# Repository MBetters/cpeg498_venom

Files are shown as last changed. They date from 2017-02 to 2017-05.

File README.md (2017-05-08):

# What Is This?
Hola. This is a UD capstone design repo for a robot spider. AKA Project Venom.

# Directories
- `spider_server`: this is a python web server that acts as the user's controller. It is hosted on c9.io.
- `spider_raspberry_pi`: this is the python code for a WiFi-connected Raspberry Pi that continuously polls `spider_server` for the latest user commands while simultaneously transmitting these commands over a serial line to the Arduino.
- `spider_arduino`: this is the Arduino code that continually listens for new commands from the serial input line from the Raspberry Pi and then translates those commands into servo signals that move the robot spider's legs.
- `spider_body`: this is STL files for 3D-printing the spider

# Summary
`spider_server` <--(WiFi)--> `spider_raspberry_pi` <--(USB)--> `spider_arduino` <--(PWM)--> servos

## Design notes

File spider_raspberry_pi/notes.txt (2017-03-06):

Installation Instructions:
pip install pyserial

Links:
http://www.ics.com/blog/raspberry-pi-camera-module#.VJFhbyvF-b8

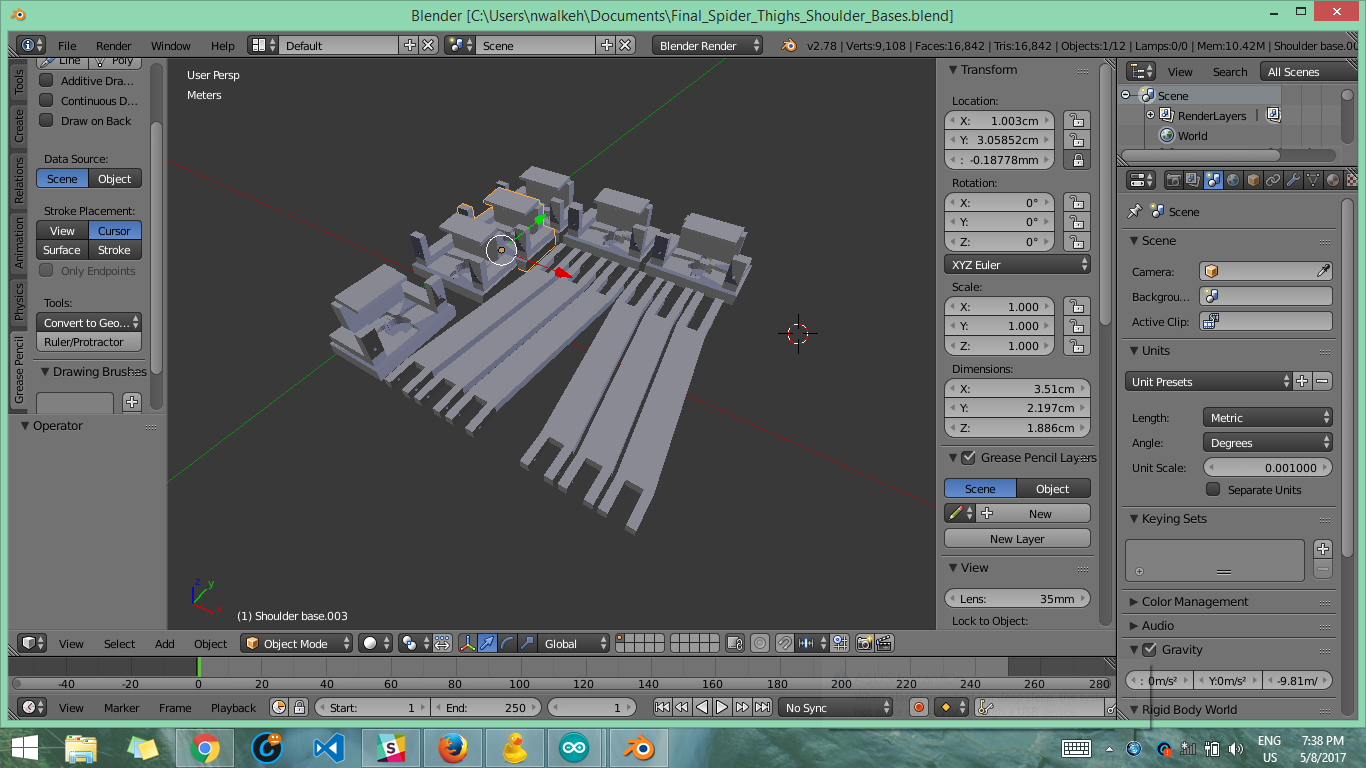
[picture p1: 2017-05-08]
spider_body/Screenshot (262).png

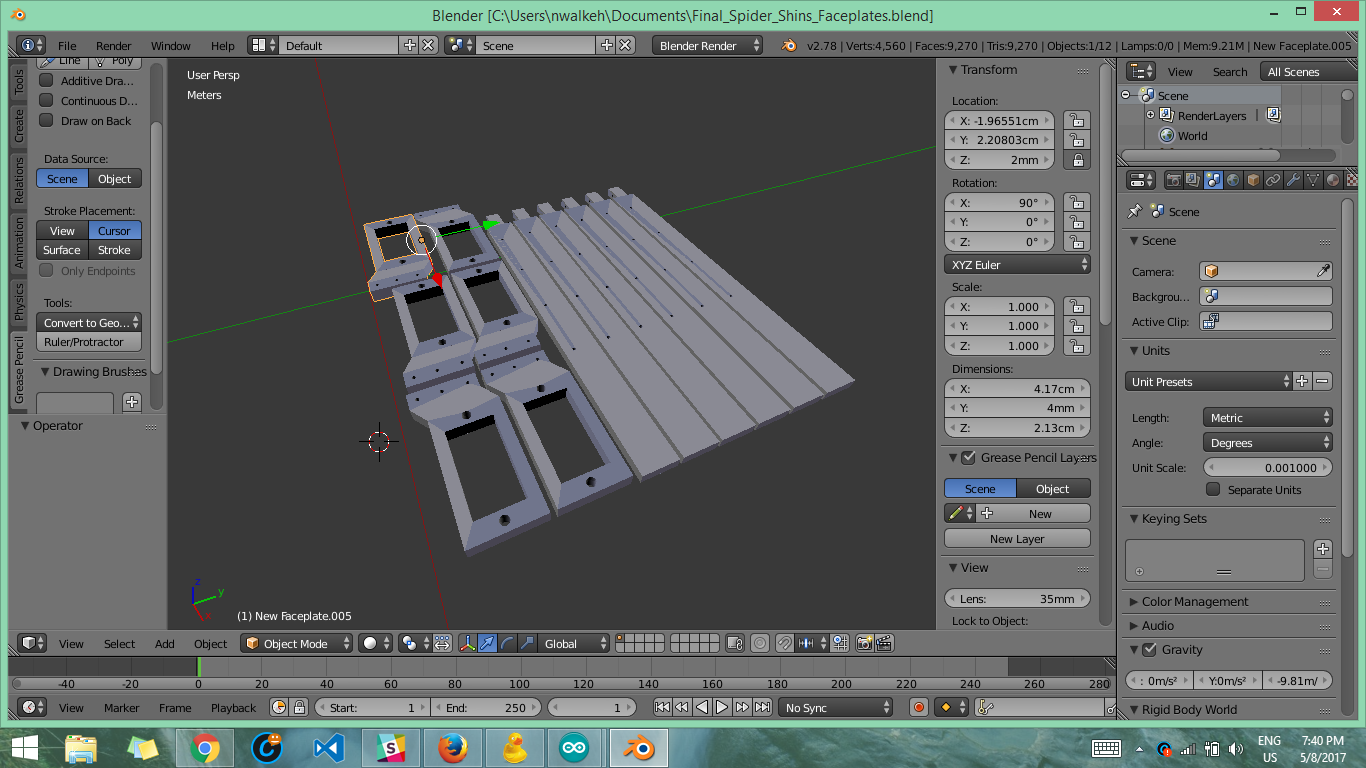
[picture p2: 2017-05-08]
spider_body/Screenshot (263).png

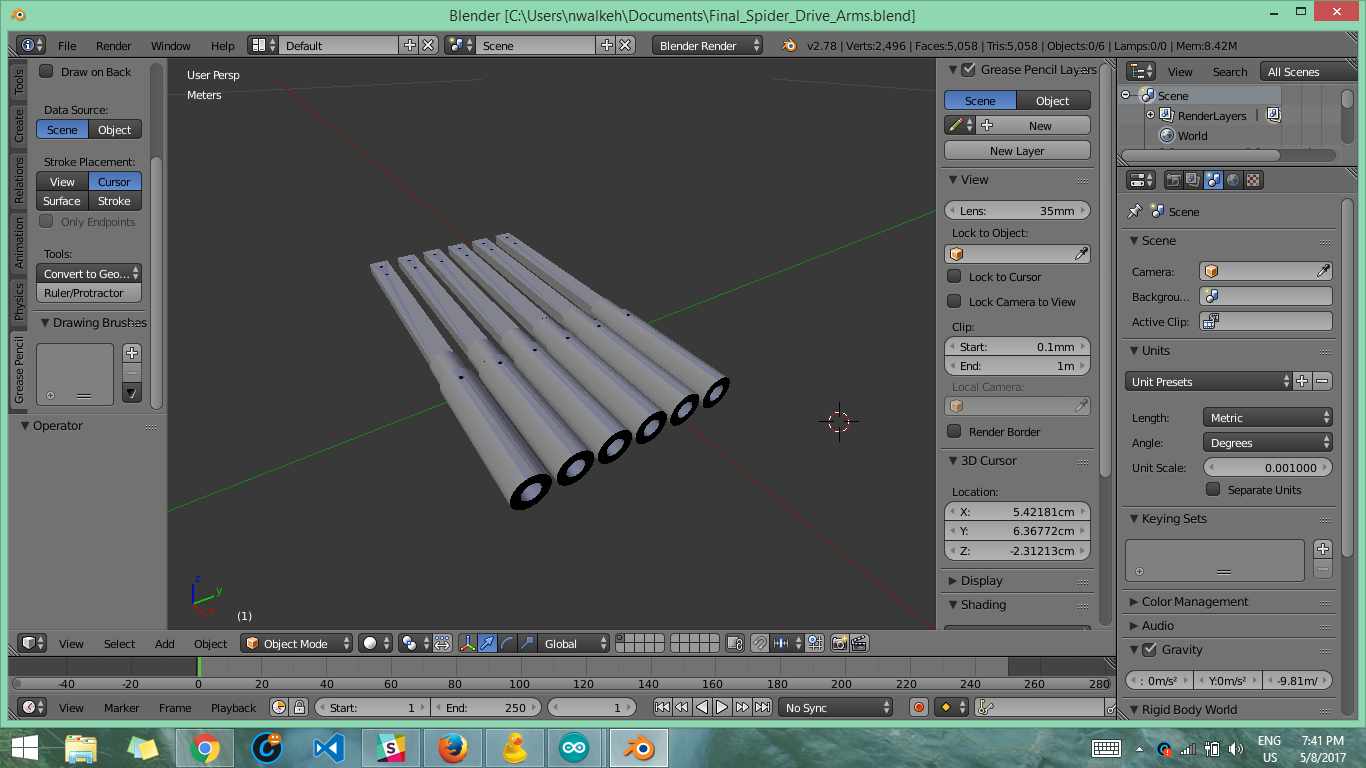
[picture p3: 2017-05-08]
spider_body/Screenshot (264).png

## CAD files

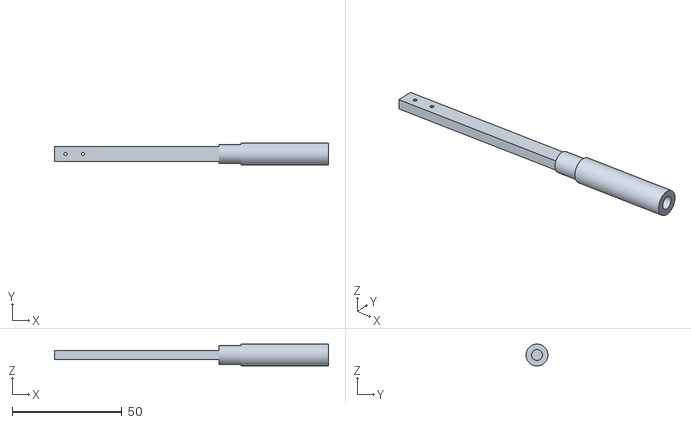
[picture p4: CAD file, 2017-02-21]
spider_body/drive_arm.stl
125.0 x 10.00 x 10.0

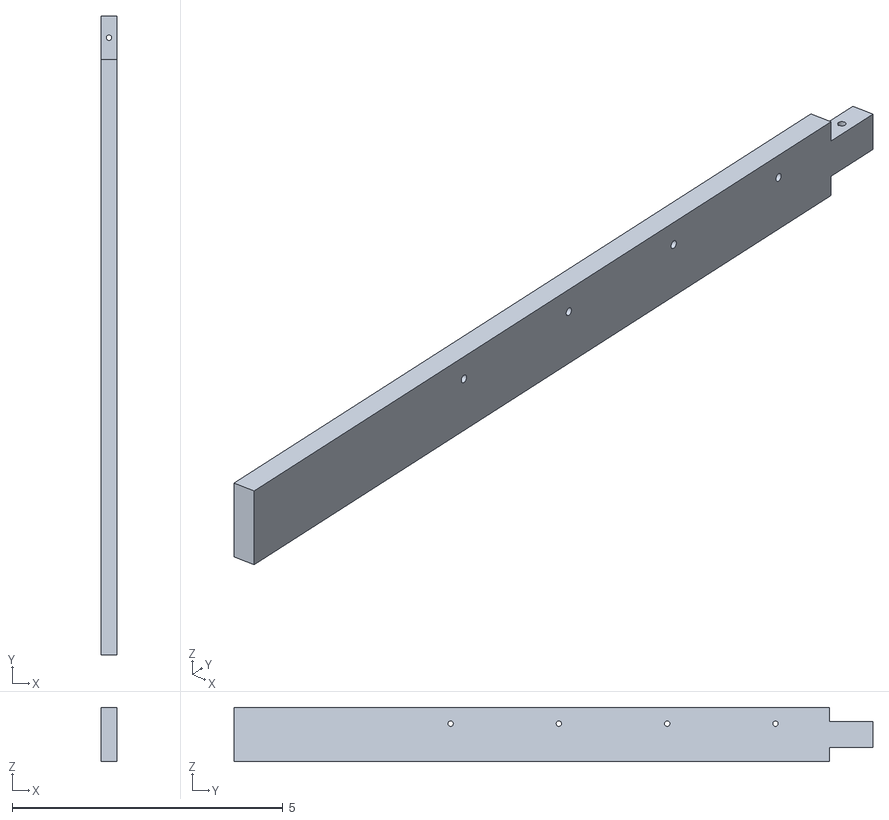
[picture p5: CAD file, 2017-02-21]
spider_body/shin.stl
0.3 x 11.8 x 1.00

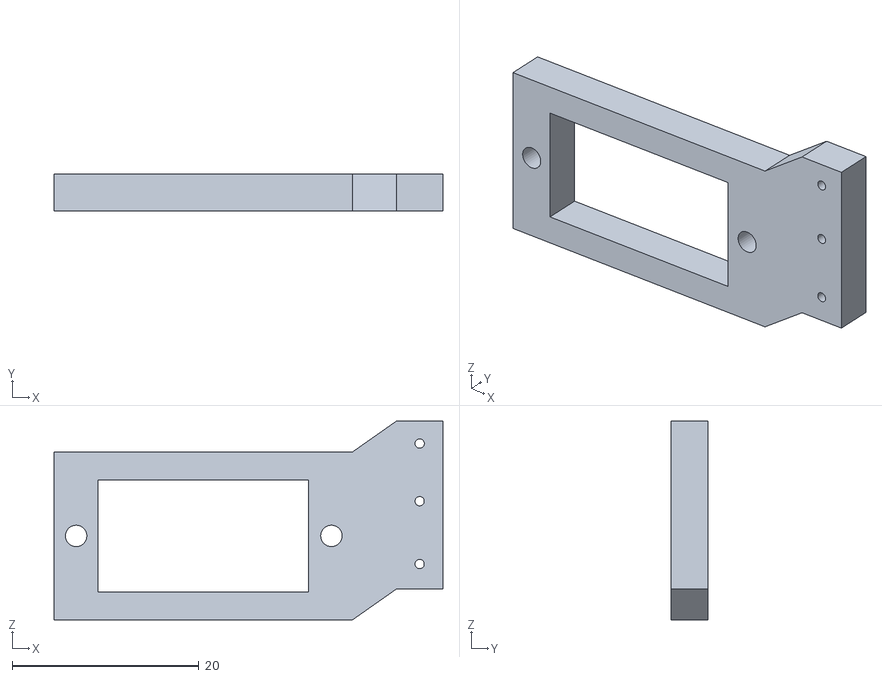
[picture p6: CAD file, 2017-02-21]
spider_body/faceplate.stl
41.7 x 4.00 x 21.3

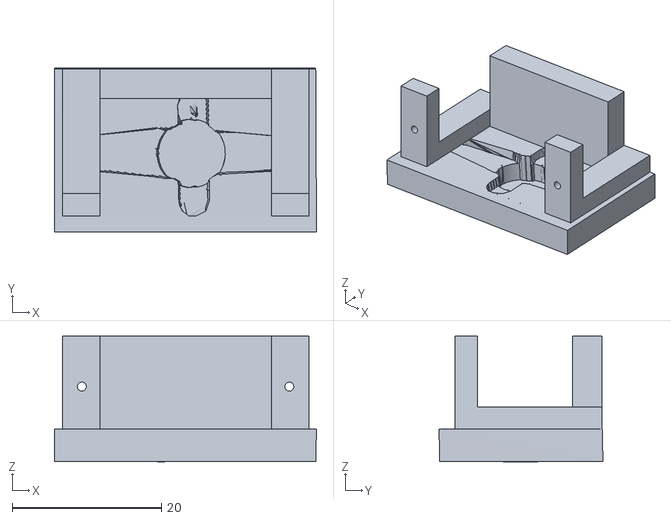
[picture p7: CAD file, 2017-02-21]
spider_body/Shoulder_base.stl
35.1 x 22.0 x 16.8

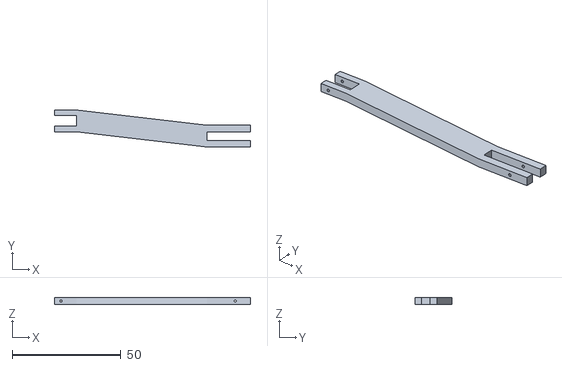
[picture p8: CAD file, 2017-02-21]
spider_body/thigh.stl
90.0 x 17.0 x 3.00

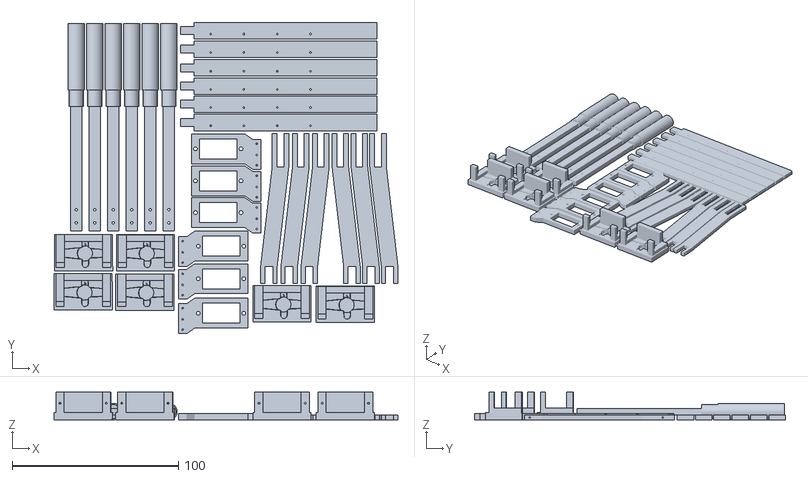
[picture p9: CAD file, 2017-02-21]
spider_body/all_spider_legs.stl
206.8 x 187.2 x 16.8

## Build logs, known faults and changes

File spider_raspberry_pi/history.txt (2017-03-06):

    1  sudo nano /etc/wpa_supplicant/wpa_supplicant.conf
    2  exit
    3  sudo nano /etc/wpa_supplicant/wpa_supplicant.conf
    4  exit
    5  sudo nano /etc/wpa_supplicant/wpa_supplicant.conf
    6  exit
    7  sudo reboot
    8  ifconfig wlan0 scan > scan.txt
    9  ifconfig wlan0 up scan > scan.txt
   10  sudo ifconfig wlan0 up scan > scan.txt
   11  ifconfifg wlan0 up
   12  ifconfig wlan0 up
   13  ifconfig wlan0
   14  dhclient -v
   15  sudo dhclient -v
   16  pciconf -lv
   17  sudo ifup wlan0
   18  iwlist wlan0 scan > scan.txt
   19  nano scan.txt
   20  sudo ifup wlan0
   21  if
   22  ifconfig
   23  ifconfig ~ more
   24  ifconfig > more
   25  more < ifconfig
   26  more <<< ifconfig
   27  ifconfig wlan0
   28  sudo dhclient -v
   29  sudo dhclient wlan0 -v
   30  sudo nano /etc/wpa_supplicant/wpa_supplicant.conf
   31  sudo service networking restart
   32  ifconfig wlan0
   33  sudo dhclient wlan0 -v
   34  sudo service networking-manager restart
   35  sudo shutdown -r now
   36  exit
   37  ifconfig wlan0
   38  ifconfig wlan0 .,l;'`12`32325467800¬!"£$%^&*()_+{}[]#~~@@
   39  grep inet < ifconfig wlan0 
   40  grep inet ifconfig wlan0 
   41  ifconfig eth0
   42  sudo nano /etc/rc.local
   43  sudo reboot
   44  sudo crontab -e
   45  ifconfig eth0
   46  ps
   47  top
   48  ps -eLf
   49  crontab -e
   50  sudo nano crontab -e
   51  crontab
   52  crontab -e
   53  sudo nano /etc/rc.local
   54  sudo /etc/init.d/launch.sh start
   55  sudo /etc/init.d/launcher.sh start
   56  sudo /etc/init.d/launcher.sh stop
   57  cd Desktop
   58  python client.py
   59  cd Desktop
   60  sudo python client.py
   61  crontab -e
   62  cd
   63  crontab -e
   64  cd
   65  crontab
   66  crontab -l
   67  crontab -r
   68  crontab -v
   69  crontab -i
   70  crontab il
   71  crontab -l
   72  ps -eLf
   73  sudo nano /ect/rc.local
   74  sudo nano /etc/init.d/launch.sh
   75  sudo nano /etc/init.d/launcher.sh
   76  exit
   77  cd Desktop
   78  sudo nano client.py
   79  sudo usermod -a -G dialout pi
   80  exit
   81  ls
   82  cd Desktop
   83  ls
   84  cd
   85  ls
   86  cd Documents
   87  ls
   88  cd
   89  cd Desktop
   90  ls
   91  cd pyserial-2.7
   92  ls
   93  sudo nano client1.py
   94  cd Desktop
   95  cd pyserial-2.7
   96  sudo python client1.py
   97  sudo nano client.py
   98  sudo nano client1.py
   99  ls
  100  nano client1.py.save
  101  python client1.py
  102  sudo nano client1.py
  103  cd Desktop
  104  cd pyserial-2.7
  105  python client1.py
  106  cd Desktop
  107  cd pyserial-2.7
  108  python client1.py
  109  sudo apt-get update
  110  sudo reboot
  111  sudo apt-get update
  112  sudo reboot
  113  sudo apt-get update
  114  sudo apt-get install python-picamera python3-picamera
  115  sudo apt=get update
  116  sudo apt-get update
  117  sudo apt-get upgrade
  118  df -h
  119  sudo apt-get upgrade
  120  cd /home/pi/oldconffiles
  121  ls
  122  ls -a
  123  cat .config
  124  cd .config
  125  ls
  126  cd
  127  sudo apt-get update
  128  sudo apt-get upgrade
  129  sudo apt-get install python-camera python3-picamera
  130  sudo apt-get install python-picamera python3-picamera
  131  raspistill -o image.jpg
  132  sudo shutdown
  133  history
  134  raspistill -o image.jpg
  135  df -h
  136  ls
  137  cat image.jpg
  138  open image.jpg
  139  ls
  140  cp image.jpg Desktop
  141  rm image.jpg
  142  ls
  143  cp delete.jpg Desktop
  144  rm delete.jpg
  145  cd Desktop
  146  rm delete.jpg
  147  cd
  148  sudo rpi-update
  149  sudo reboot
  150  history
  151  history > hist.txt

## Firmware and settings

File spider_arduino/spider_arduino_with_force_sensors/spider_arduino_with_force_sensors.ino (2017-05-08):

///////////////////////////////////////
//SECTION: Global Variable Definitions
///////////////////////////////////////
unsigned int FLS = 32; //front-left shoulder pin number
unsigned int FLE = 21; //front-left elbow pin number
unsigned int FRS = 10; //front-right shoulder pin number
unsigned int FRE = 20; //front-right elbow pin number
unsigned int BLS = 25; //back-left shoulder pin number
unsigned int BLE = 22; //back-left elbow pin number
unsigned int BRS = 6; //back-right shoulder pin number
unsigned int BRE = 9; //back-right elbow pin number
unsigned int MLS = 4; //middle-left shoulder
unsigned int MLE = 23; //middle-left elbow
unsigned int MRS = 5; //middle-right shoulder
unsigned int MRE = 3; //middle-right elbow

// Current pins being used by servos: 3, 4, 5, 6, 9, 10, 20, 21, 22, 23, 25, 32
// Possible pins for each force sensor: 14, 15, 16, 17, 18, 19
unsigned int fsrFLL = 14; // FSR for Front Left Leg
unsigned int fsrBLL = 16; // Back Left Leg 
unsigned int fsrFRL = 17; // Front Right Leg
unsigned int fsrBRL = 19; // Back Right Leg


unsigned int servoPinNumbers[] = {FLS, FLE, 
                                  FRS, FRE,
                                  BLS, BLE,
                                  BRS, BRE,
                                  MLS, MLE,
                                  MRS, MRE};

String servoNames[] = {"FLS", "FLE", 
                       "FRS", "FRE",
                       "BLS", "BLE",
                       "BRS", "BRE",
                       "MLS", "MLE",
                       "MRS", "MRE"};

// Denotes current, actual PWM output, NOT the desired postion it's moving toward. Begins at standing position.
float currentPos[12] = {800, 200, 
                        800, 200, 
                        300, 200, 
                        300, 200,
                        600, 200,
                        600, 200};

// Desired PWM position, which currentPosition slowly moves towards over a few loop() cycles.
int desiredPos[12] = {800, 200, 
                      800, 200, 
                      300, 200, 
                      300, 200,
                      600, 200,
                      600, 200};

// Updated every new step in a sequence- array is used to know total distance from start to finish for each servo,
// so that they can run at the speed required for them to all finish at the same time.
int totalDistance[12] = {0, 0, 0, 0, 0, 0, 0, 0, 0, 0, 0, 0};

// Needed to compensate for loss of precision throughout movement increments.
float remainders[12] = {0.0, 0.0, 0.0, 0.0, 0.0, 0.0, 0.0, 0.0, 0.0, 0.0, 0.0, 0.0};

// Variable that keeps track of what the 'lowest' point is for the spider, to know that if a knee is low enough it 'should' be touching the ground.
unsigned int lowPoint = 0;
unsigned int SPEED = 0;

unsigned int servoPWMValueBounds[12][2] = {{8600, 2200},
                                           {1660, 5500},
                                           {1790, 7700},
                                           {7410, 2750},
                                           {8500, 3800},
                                           {1970, 6100},
                                           {2000, 6500},
                                           {8080, 3700},
                                           {8000, 3800},
                                           {1680, 5600},
                                           {1450, 4500},
                                           {8450, 3000}};

unsigned int PWMMin = 3277;
unsigned int PWMMax = 6553;

unsigned int servoID = 0;

unsigned int* PWMValues[12];
unsigned int PWMValuesIndex = 0;
unsigned int numberOfPWMValues = 0;

unsigned int DOWN = 200;
unsigned int UP = 500;
unsigned int FORWARD[3] = {700, 450, 700};
unsigned int CENTEr[3] = {600, 350, 600};
unsigned int BACK[3] = {500, 250, 500};

unsigned int STAND_ARRAY_LENGTH = 1;
unsigned int STAND_SPEED = 100;
unsigned int PWMValuesStand[12][1] = {
  {CENTEr[0]},
  {DOWN     },
  {CENTEr[0]},
  {DOWN     },
  {CENTEr[1]},
  {DOWN     },
  {CENTEr[1]},
  {DOWN     },
  {CENTEr[2]},
  {DOWN     },
  {CENTEr[2]},
  {DOWN     }
};

unsigned int CROUCH_ARRAY_LENGTH = 1;
unsigned int CROUCH_SPEED = 100;
unsigned int PWMValuesCrouch[12][1] = {
  {CENTEr[0]},
  {UP       },
  {CENTEr[0]},
  {UP       },
  {CENTEr[1]},
  {UP       },
  {CENTEr[1]},
  {UP       },
  {CENTEr[2]},
  {UP       },
  {CENTEr[2]},
  {UP       }
};

unsigned int WALK_SPEED = 100;
unsigned int WALK_ARRAY_LENGTH = 6;
unsigned int PWMValuesWalk[12][6] = {
  {FORWARD[0], FORWARD[0], FORWARD[0], BACK[0]   , BACK[0]   , BACK[0]   }, //FLS >>><<<
  {UP        , DOWN      , DOWN      , DOWN      , DOWN      , UP        }, //FLE -____-
  {BACK[0]   , BACK[0]   , BACK[0]   , FORWARD[0], FORWARD[0], FORWARD[0]}, //FRS <<<>>>
  {DOWN      , DOWN      , UP        , UP        , DOWN      , DOWN      }, //FRE __--__
  {FORWARD[1], FORWARD[1], FORWARD[1], BACK[1]   , BACK[1]   , BACK[1]   }, //BLS >>><<<
  {UP        , DOWN      , DOWN      , DOWN      , DOWN      , UP        }, //BLE -____-
  {BACK[1]   , BACK[1]   , BACK[1]   , FORWARD[1], FORWARD[1], FORWARD[1]}, //BRS <<<>>>
  {DOWN      , DOWN      , UP        , UP        , DOWN      , DOWN      }, //BRE __--__
  {BACK[2]   , BACK[2]   , BACK[2]   , FORWARD[2], FORWARD[2], FORWARD[2]}, //MLS <<<>>>
  {DOWN      , DOWN      , UP        , UP        , DOWN      , DOWN      }, //MLE __--__
  {FORWARD[2], FORWARD[2], FORWARD[2], BACK[2]   , BACK[2]   , BACK[2]   }, //MRS >>><<<
  {UP        , DOWN      , DOWN      , DOWN      , DOWN      , UP        }  //MRE -____-
};

unsigned int JUMP_ARRAY_LENGTH = 7;
unsigned int JUMP_SPEED = 100;
unsigned int PWMValuesJump[12][7] = {
  {800, 800, 800, 800, 800, 800, 800}, //FLS
  {200, 300, 400, 500, 600, 100, 200}, //FLE
  {800, 800, 800, 800, 800, 800, 800}, //FRS
  {200, 300, 400, 500, 600, 100, 400}, //FRE
  {300, 300, 300, 300, 300, 300, 300}, //BLS
  {200, 300, 400, 500, 600, 100, 200}, //BLE
  {300, 300, 300, 300, 300, 300, 300}, //BRS
  {200, 300, 400, 500, 600, 100, 400}, //BRE
  {600, 600, 600, 600, 600, 600, 600}, //MLS
  {200, 300, 400, 500, 600, 100, 300}, //MLE
  {600, 600, 600, 600, 600, 600, 600}, //MRS
  {200, 300, 400, 500, 600, 100, 300}  //MRE
};

////////////////////////////////////////
//SECTION: setup() and loop() Functions
////////////////////////////////////////
void setup() {

  //Good resource on Teensy PWM capabilities: https://www.pjrc.com/teensy/td_pulse.html
  
  //Set all PWM pins to have freq=50Hz.
  //Why 50Hz?
  //Answer: Because we need the PWM pins operating with a 20ms period,
  //        since that's what the SG90 Servo datasheet says is the operating period.
  //Note that you couldn't set these pins to different frequencies even if you tried,
  //since some of the pins share on-board timers and therefore must have the same frequency.
  analogWriteFrequency(FLS, 50);
  analogWriteFrequency(FLE, 50);
  analogWriteFrequency(FRS, 50);
  analogWriteFrequency(FRE, 50);
  analogWriteFrequency(BLS, 50);
  analogWriteFrequency(BLE, 50);
  analogWriteFrequency(BRS, 50);
  analogWriteFrequency(BRE, 50);
  analogWriteFrequency(MLS, 50);
  analogWriteFrequency(MLE, 50);
  analogWriteFrequency(MRS, 50);
  analogWriteFrequency(MRE, 50);

  //Set the PWM resolution to 16 bits, 
  //so that the analogWrite function can accept values 
  //in the range of 0 - 65535 (2^16 - 1),
  //where 0 is 0% duty cycle and 65535 is 100% duty cycle.
  //The servos accept a duty cycle range of 5% to 10%,
  //so analogWrite values should range from 3277 to 6553.
  //These values are set to PWMMin and PWMMax, respectively.
  analogWriteResolution(16);

  //Open a serial communication line with data rate = 9600 bits per second.
  //NOTE: The Raspberry Pi sends commands and the Arduino receives them.
  //      In the future, the Arduino will send the latest distance sensor values
  //      back to the Raspberry Pi.
  //NOTE: Make sure that the Raspberry Pi has a matching bit transmission rate,
  //      so that the Arduino is receiving new bits at the same rate that the 
  //      Raspberry Pi is sending them and vise versa.
  Serial.begin(9600);

  //Run all the tests.
  //runTests(); //Comment this out in production, so that it doesn't run.
  
  //turnOn();
  //TO START OUT WALKING:
  //for (int i=0; i < 12; i++) PWMValues[i] = PWMValuesWalk[i];
  //    numberOfPWMValues = WALK_ARRAY_LENGTH;
  //    SPEED = WALK_SPEED;
  
  Serial.println("setup done");
}

void loop() {

  //Get the current action.
  if (Serial.available()) {
    char ch = Serial.read();
    //Here, the Arduino reads serial USB input, 
    //which will be commands (in the form of characters) coming from the RaspberryPi.
    //To test these serial inputs out on a computer, use Tools->Serial Monitor.
    if (ch == 's') {
      Serial.println("Received 'stand up' command");
      for (int i=0; i < 12; i++) PWMValues[i] = PWMValuesStand[i];
      numberOfPWMValues = STAND_ARRAY_LENGTH;
      SPEED = STAND_SPEED;
    }
    else if (ch == 'w') {
      Serial.println("Received 'move forward' command");
      for (int i=0; i < 12; i++) PWMValues[i] = PWMValuesWalk[i];
      numberOfPWMValues = WALK_ARRAY_LENGTH;
      SPEED = WALK_SPEED;
    }
    else if (ch == 'j') {
      Serial.println("Received 'jump' command");
      for (int i=0; i < 12; i++) PWMValues[i] = PWMValuesJump[i];
      numberOfPWMValues = JUMP_ARRAY_LENGTH;
      SPEED = JUMP_SPEED;
    }
    else if (ch == 'c') {
      Serial.println("Received 'crouch' command");
      for (int i=0; i < 12; i++) PWMValues[i] = PWMValuesCrouch[i];
      numberOfPWMValues = CROUCH_ARRAY_LENGTH;
      SPEED = CROUCH_SPEED;
    }
    //Reset the PWMValuesIndex to zero.
    PWMValuesIndex = 0;
  }

  //If the PWMValuesIndex hasn't reached the end of the 2D action array,
  //then keep running the action.
  if (PWMValuesIndex < numberOfPWMValues && compareArray(currentPos, desiredPos)) {
    // Reset lowPoint
    lowPoint = 1000;
    Serial.print("Next step: ");
    Serial.println(PWMValuesIndex);
    //Update desiredPos for every servo
    for (servoID = 0; servoID < 12; servoID++) {
      //Get the proportional (between 0 and 1000) PWM value
      int proportionalPWMValue = PWMValues[servoID][PWMValuesIndex];
      // Update with the start-to-finish distance for the servo.
      totalDistance[servoID] = proportionalPWMValue - currentPos[servoID];
      //Actuate the servo with the PWM value
      desiredPos[servoID] = proportionalPWMValue;
      //Update lowPoint variable to reevaluate the lowest elbow value for the next step
      if (servoID % 2 == 1 && lowPoint > proportionalPWMValue) lowPoint = proportionalPWMValue;
    }
    //Increment PWMValuesIndex
    PWMValuesIndex++;
  } else if (!compareArray(currentPos, desiredPos)) {
    //PWMIncrement();
    //Have a small delay before the next call to loop()
    delay(4);
  } else {
    //If the end of the action sequence has been reached, start over and repeat until new command is received.
    PWMValuesIndex = 0;
  }

   getSensorRead(fsrFLL); // Gets sensor reading for FLL and outputs its respective value.
  getSensorRead(fsrBRL);
  getSensorRead(fsrFRL);
  getSensorRead(fsrBRL);
}

//////////////////////////////
//SECTION: Movement Functions
//////////////////////////////

/*void PWMIncrement() {
  int val = analogRead(0);
  Serial.print("analog 0 is: ");
  Serial.println(val);
  // Takes an incremental step towards the 'desiredPos' array, updating the analog PWM output and the currentPos array to reflect that.
  for (servoID = 0; servoID < 12; servoID++) {
    //Find the distance required for the servo to move 1/n of the way to the destination.
    float stepSize = ((float) totalDistance[servoID]) / SPEED;
    //Add (or implicitly subtract) the step size from the current servo position
    float nextProportionalPWMValue = currentPos[servoID] + stepSize;
    // Near the end, numbers may need to be rounded so they perfectly end up where they should
    if (abs(nextProportionalPWMValue - desiredPos[servoID]) < abs(stepSize)) {
      nextProportionalPWMValue = desiredPos[servoID];
    }*/
    //Get the actual PWM value
    unsigned int PWMValue = translateBounds(servoID, (int) nextProportionalPWMValue);
    //Update what our current PWM output is for this servo
    currentPos[servoID] = nextProportionalPWMValue;
    //Get the servo pin number
    unsigned int servoPinNumber = servoPinNumbers[servoID];
    //Actuate the servo with the PWM value
    analogWrite(servoPinNumber, PWMValue);
  }
}

void turnOn() {
  // Assumes a folded position of elbows at 700, shoulders at 0.
  for (int i=0; i < 100; i++) {
    delay(20); // Whole process takes 2 seconds: 100 * 20ms = 2000ms
    analogWrite(FLS, translateBounds(0, i * 8));
    analogWrite(FRS, translateBounds(2, i * 8));
    analogWrite(BLS, translateBounds(4, i * 3));
    analogWrite(BRS, translateBounds(6, i * 3));
    analogWrite(MLS, translateBounds(8, i * 6));
    analogWrite(MRS, translateBounds(10, i * 6));
  }
  for (int i=700; i > 200; i--) {
    delay(4); // Whole process takes 2 seconds: 500 * 4ms = 2000ms
    analogWrite(FLE, translateBounds(1, i));
    analogWrite(FRE, translateBounds(3, i));
    analogWrite(BLE, translateBounds(5, i));
    analogWrite(BRE, translateBounds(7, i));
    analogWrite(MLE, translateBounds(9, i));
    analogWrite(MRE, translateBounds(11, i));
  }
}

void turnOff() {
  // Assumes a standing position of elbows at 200.
  for (int i=200; i < 700; i++) {
    delay(4); // Whole process takes 2 seconds: 500 * 4ms = 2000ms
    analogWrite(FRE, translateBounds(3, i));
    analogWrite(FLE, translateBounds(1, i));
    analogWrite(BRE, translateBounds(7, i));
    analogWrite(BLE, translateBounds(5, i));
    analogWrite(MRE, translateBounds(11, i));
    analogWrite(MLE, translateBounds(9, i));
  }
  for (int i=100; i > 0; i--) {
    delay(20); // Whole process takes 2 seconds: 100 * 20ms = 2000ms
    analogWrite(FRS, translateBounds(2, i * 8));
    analogWrite(FLS, translateBounds(0, i * 8));
    analogWrite(BRS, translateBounds(6, i * 3));
    analogWrite(BLS, translateBounds(4, i * 3));
    analogWrite(MRS, translateBounds(10, i * 6));
    analogWrite(MLS, translateBounds(8, i * 6));
  }
  //resetFunc(); //call reset 
}

////////////////////////////
//SECTION: Helper Functions
////////////////////////////

boolean compareArray(float *a, int *b){
  int n;
  // test each element to be the same. if not, return false
  for (n=0; n < 12; n++) {
    if (a[n] != b[n]) return false;
  }
  return true;
}

unsigned int translateBounds(unsigned int servoIndex, int value) {
  // This function maps input values from 0-1000 to the corresponding ranges for each servo, so they are 
  // calibrated to each other and none of them goes out of range and damages the robot. 
  // 0 for elbows means pushed all the way down, and 0 for shoulders means pushed all the way back.
  // 1000 for elbows means pushed all the way up (legs in the air), and 1000 for shoulders means pushed all the way forward.
  //
  // So, moving all elbows down together might look like this:
  //
  // unsigned int allElbows = 100;
  //
  // analogWrite(FRE, translateBounds("FRE", allElbows));
  // analogWrite(FLE, translateBounds("FLE", allElbows));
  // analogWrite(BRE, translateBounds("BRE", allElbows));
  // analogWrite(BLE, translateBounds("BLE", allElbows));
  // analogWrite(MRE, translateBounds("MRE", allElbows));
  // analogWrite(MLE, translateBounds("MLE", allElbows));

  if (value > 1000) Serial.println("ERROR: value over 1000");
  else if (value < 0) Serial.println("ERROR: value less than 0");
  else if (servoPWMValueBounds[servoIndex][0] < servoPWMValueBounds[servoIndex][1]) {
    return (unsigned int) ((servoPWMValueBounds[servoIndex][1]
                          - servoPWMValueBounds[servoIndex][0]) * value / 1000)
                          + servoPWMValueBounds[servoIndex][0];
  } else {
    return (unsigned int) servoPWMValueBounds[servoIndex][0] 
                          - ((servoPWMValueBounds[servoIndex][0]
                            - servoPWMValueBounds[servoIndex][1]) * value / 1000);
  }
  //Something is wrong, so program is effectively stopped here.
  while(1);
}

/////////////////
//SECTION: Tests
/////////////////
void runTests() {
  //This function runs one or more tests.
  testPWMPin(10);
}

void testPWMPin(unsigned int PWMPinNumber) {
  unsigned int i = PWMMin;
  while (i < PWMMax) {
    analogWrite(PWMPinNumber, i);
    i = i + 1;
    delay(1);
  }
}


/////////////////
//SECTION: Force
/////////////////
unsigned int getSensorRead(unsigned int SensorPinNumber)
{
  if (SensorPinNumber == 14)
  {
    Serial.print("FLL reading = ");
    Serial.println(analogRead(SensorPinNumber));
  }
  else if (SensorPinNumber == 16)
  {
    Serial.print("BLL reading = ");
    Serial.println(analogRead(SensorPinNumber));
  }
  else if (SensorPinNumber == 17)
  {
    Serial.print("FRL reading = ");
    Serial.println(analogRead(SensorPinNumber));
  }
  else if (SensorPinNumber == 19)
  {
    Serial.print("BRL reading = ");
    Serial.println(analogRead(SensorPinNumber));
  }
  
}

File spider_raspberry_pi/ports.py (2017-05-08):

import sys
import glob
import serial


def serial_ports():
    """ Lists serial port names

        :raises EnvironmentError:
            On unsupported or unknown platforms
        :returns:
            A list of the serial ports available on the system
    """
    if sys.platform.startswith('win'):
        ports = ['COM%s' % (i + 1) for i in range(256)]
    elif sys.platform.startswith('linux') or sys.platform.startswith('cygwin'):
        # this excludes your current terminal "/dev/tty"
        ports = glob.glob('/dev/tty[A-Za-z]*')
    elif sys.platform.startswith('darwin'):
        ports = glob.glob('/dev/tty.*')
    else:
        raise EnvironmentError('Unsupported platform')

    result = []
    for port in ports:
        try:
            s = serial.Serial(port)
            s.close()
            result.append(port)
        except (OSError, serial.SerialException):
            pass
    return result


if __name__ == '__main__':
    print serial_ports()

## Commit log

2017-02-21 Sonar
    Sonar Code for Arduino
2017-02-21 Stl file - 6 Legs
    Stl file that includes all parts needed to make 6 legs.
    [Final_Spider_Legs.stl]
2017-02-21 changed 'javascript' to 'arduino' code
2017-02-21 Stl - thigh
    [thigh_simple.stl]
2017-02-21 Stl - Shoulder base
    [Shoulder_base.stl]
2017-02-21 Stl - Faceplate
    [New_Faceplate.stl]
2017-02-21 Stl - foot/shin
    [foot_simple.stl]
2017-02-21 Stl - drive arm
    [driveArm.stl]
2017-02-22 Revert "Sonar"
    This reverts commit 796181d4c3c8073d10b8f77b469b740c406f3268.
2017-02-22 Revert "Revert "Sonar""
    This reverts commit de527ce96ff7552e1a528036994d593eccfc40a0.
2017-02-22 Code for Two Sonars
2017-03-09 Restructured files
    [Final_Spider_Legs.stl, New_Faceplate.stl, Shoulder_base.stl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]
2017-03-11 Started implementing movements with 3D array and added a way to get PWM values proportionally
2017-03-11 Renamed the STL files
    [all_spider_legs.stl, drive_arm.stl, faceplate.stl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]
2017-03-11 Add translateBounds function at end of file
    this function maps input values from 0-1000 to the corresponding ranges for each servo, so they are calibrated to each other and none of them goes out of range and damages the robot. 0 for elbows means pushed all the way down, and 0 for shoulders means pushed all the way back.
2017-03-13 Update servo pin numbers - all are correct now
2017-04-03 Removed servoName, since it's not used
2017-04-03 Add PWMIncrement() function
    Allows simple motion sequences to be entered when defining motion, and adds a layer of abstraction to automatically smooth the servo movement over a fixed period of time for each step in the sequence.
2017-04-04 Fix PWM array reassignment
2017-04-04 change currentPos to float array
2017-04-04 Force Sensor Code
    Should be able to just copy and paste it over. Discuss next meeting.
2017-04-05 Add lowPoint global variable
    Keeps track of the lowest elbow variable, to know what legs 'should' be
    touching the ground at any step. Will help with force sensor logic.
2017-04-06 Cleaned up force sensor code
2017-04-06 updated/cleaned sensor code
2017-04-06 Updated force sensor code
2017-04-11 Add groundwork for trig layer
2017-04-14 Spider with sonar (Please Read Description)
    Make sure to change the pin numbers for the two sonars according to what pins are available. Use analog pins.
2017-04-14 updated sonar code
2017-05-01 Change to Sonar pin info
2017-05-08 Removed conflicts and Updated force sensors
2017-05-08 Pushed code for spider with force sensors
    Tried to complie/verify the sketch but got an error:
    'shoulderServoPinNumber' was not declared in this scope
    [spider_arduino_with_force_sensors.ino]
2017-05-08 added force sensor
2017-05-22 Update spider_motion_ardu.ino
    Final Arduino code
